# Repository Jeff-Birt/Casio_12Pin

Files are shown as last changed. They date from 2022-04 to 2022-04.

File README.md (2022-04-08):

A homemade connector for the Casio pocket computer 12-pin accessory connector.

I tried to keep the number of uncommon tools used to a minimum. A 3D printer was used to make the enclosure, but many people have access to a printer these days. A bench-top metal shear which was used to cut 0.025" brass strip to make the connector pins.

The special OSHpark CAM profile was used to get the plated though slots to come out correctly in Eagle.

A video showing how the connector was designed can be found at: https://youtu.be/ZkhR9M4t50I

EDIT: 08 April, 2022 - moved holes for ribbon cable 0.050" inward.

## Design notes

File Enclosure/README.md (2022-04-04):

3D printed enclosure for the conenctor PCB. I printed with a 0.15mm layer height with support under the two 'prongs' that stick out.

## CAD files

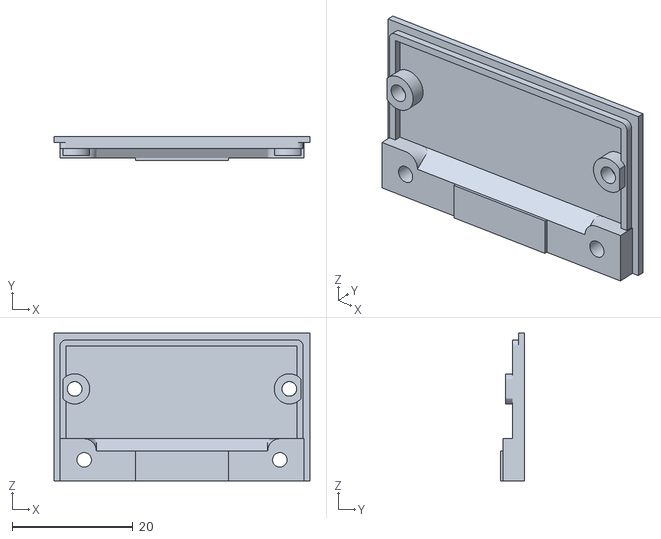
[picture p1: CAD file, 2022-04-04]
Enclosure/Tabbed_Enclosure_Lid.stl
42.4 x 4.00 x 24.5

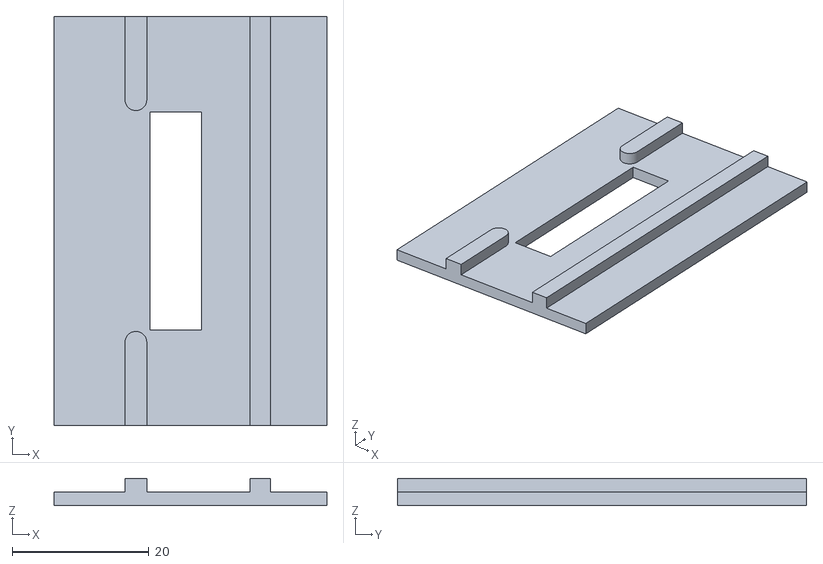
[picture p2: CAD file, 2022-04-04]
Soldering_Fixture/Soldering_Fixture.stl
40.0 x 60.0 x 4.00

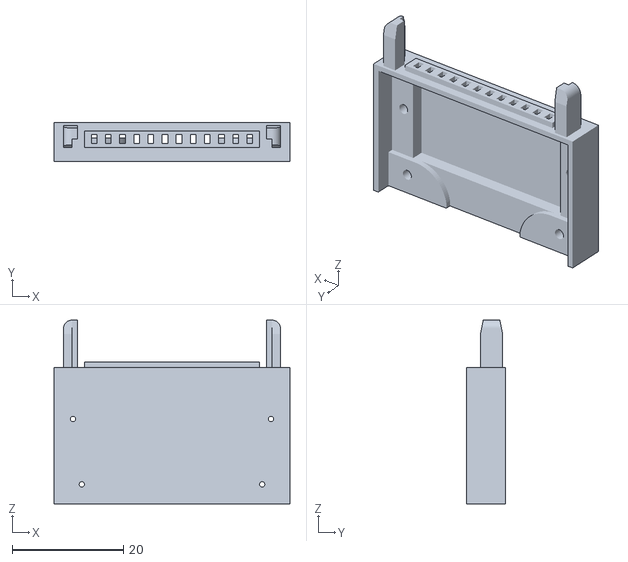
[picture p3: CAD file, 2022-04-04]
Enclosure/Tabbed_Enclosure_Bottom.stl
42.4 x 7.00 x 33.0

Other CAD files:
Enclosure/PB-100_SlotCon_Housing v43.f3d

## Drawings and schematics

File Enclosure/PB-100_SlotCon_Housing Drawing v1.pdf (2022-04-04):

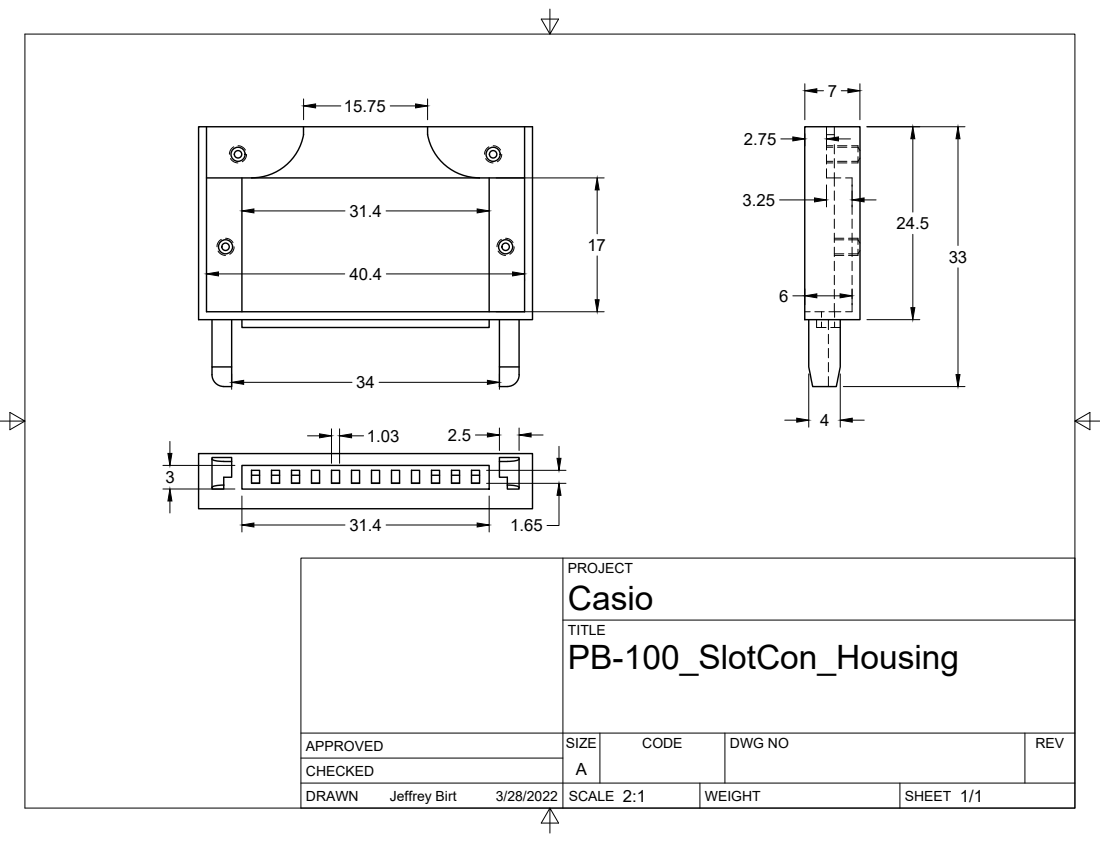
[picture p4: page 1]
SIZE; CODE; DWG NO; REV; Jeffrey Birt

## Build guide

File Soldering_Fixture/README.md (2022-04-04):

This is a simple assembly fixture to keep pins aligned while soldering. I put two layers of Kapton tape down in the areas that got hot as some protection. This is only partially effective so this fixture is good for only a few connectors unless pritned in a high-temp material.
